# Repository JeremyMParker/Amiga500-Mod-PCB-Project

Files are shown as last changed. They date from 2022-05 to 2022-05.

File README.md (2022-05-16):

# Amiga500-Mod-PCB-Project
A small back panel PCB to house HDMI and several switches...
This small 4-layer PCB will take an HDMI mini cable from a Raspberry Pi RGB-to-HDMI and convert to normal size HDMI for plugging into the Amiga.
There is one small SPST push-button switch to allow menu access to the Raspberry Pi by way of a 2-pin 100mil spaced header.
A miniture DPDT switch is wired to a 4-pin 100mil header to allow the Amiga-Kit DF0/DF1 select switch cable to plug right in.
A miniture 3PDT switch is wired to a 4-pin 100mil header to allow access to the Amiga Audio Filter Mod as described in my YouTube video.
The Audio Filter control either lets the Amiga control the output low-pass filters, or overrides the Amiga and forces the filters to be enabled/disabled.
The PCB is just barely wide enough to fit in the blank space on the left side of the A500 when looking at the back.
This is my first GitHub repository, so please be patient with me!
IMG_4756 copy

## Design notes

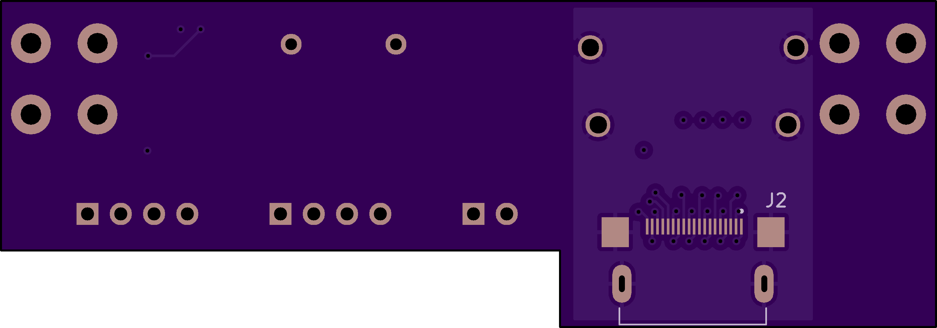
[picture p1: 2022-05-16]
Amiga500 Mod PCB Rev A CAM/OSH Park CAM/Amiga500 Mod PCB RevA bottom.png

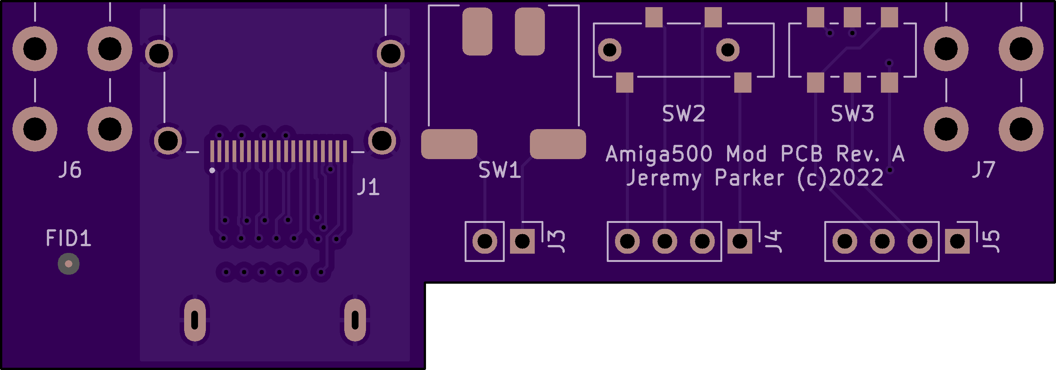
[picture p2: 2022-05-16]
Amiga500 Mod PCB Rev A CAM/OSH Park CAM/Amiga500 Mod PCB RevA top.png

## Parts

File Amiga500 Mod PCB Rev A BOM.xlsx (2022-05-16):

Item | Qty | Reference(s) | Value | LibPart | Footprint | MANUFACTURER | Digi-Key Description | Digi-Key Order #
1 | 1 | J1 | DC04S019JA1R600 | JP Symbol Library:DC04S019JA1R600_2 | SnapEDA Library:JAE_DC04S019JA1R600 | JAE | RECEPT, HDMI 2.1, 48GBPS BANDWID | 670-3154-1-ND
2 | 1 | J2 | 2013978-1 | 2013978-1:2013978-1 | SnapEDA Library:TE_2013978-1 | TE Connectivity | CONN RCPT MINI HDMI 19POS SMD RA | A107963CT-ND
3 | 1 | J3 | Conn_01x02_Male | Connector:Conn_01x02_Male | Connector_PinHeader_2.54mm:PinHeader_1x02_P2.54mm_Vertical | Hirose | CONN HEADER VERT 2POS 2.54MM | H123034-ND
4 | 2 | J4, J5 | Conn_01x04_Male | Connector:Conn_01x04_Male | Connector_PinHeader_2.54mm:PinHeader_1x04_P2.54mm_Vertical | Hirose | CONN HEADER VERT 4POS 2.54MM | H123038-ND
5 | 2 | J6, J7 | Screw_Terminal_01x04 | Connector:Screw_Terminal_01x04 | JP Library:Keystone 4-40 screw terminal | Keystone | TERM SCREW 4-40 4 PIN PCB RA | 36-7774-ND
6 | 1 | SW1 | SW_Push | Switch:SW_Push | JP Library:SPST 800BWSP9SM6RE | E-Switch | SWITCH PUSH SPST-NO 0.4VA 20V | EG2610CT-ND
7 | 1 | SW2 | SW_SP3T | Switch:SW_SP3T | JP Library:SP3T CL-SB-13B-11T | Nidec Copal Electronics | SWITCH SLIDE SP3T 200MA 12V | 563-1332-1-ND
8 | 1 | SW3 | SW_DPDT_x2 | Switch:SW_DPDT_x2 | JP Library:DPDT CL-SB-22B-12T | Nidec Copal Electronics | SWITCH SLIDE DPDT 200MA 12V | 563-1345-1-ND

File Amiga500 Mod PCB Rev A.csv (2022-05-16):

Source: | C:\Users\Jeremy\Documents\PCB Designs\Amiga500 Mod PCB Rev A.kicad_sch
Date: | 5/14/2022 9:10:37 PM
Tool: | Eeschema (6.0.2)
Generator: | C:\Program Files\KiCad\6.0\bin\scripting\plugins/bom_csv_grouped_by_value.py
Component Count: | 11
Individual Components:
Item | Qty | Reference(s) | Value | LibPart | Footprint | Datasheet | MANUFACTURER | MAXIMUM_PACKAGE_HEIGHT | PARTREV | STANDARD
 |  | FID1 | Fiducial | Mechanical:Fiducial | Fiducial:Fiducial_0.5mm_Mask1.5mm | ~
 |  | J1 | DC04S019JA1R600 | JP Symbol Library:DC04S019JA1R600_2 | SnapEDA Library:JAE_DC04S019JA1R600 |  | JAE | 6.3 mm | 1 | Manufacturer Recommendations
 |  | J2 | 2013978-1 | 2013978-1:2013978-1 | SnapEDA Library:TE_2013978-1 |  | TE Connectivity | 3.45mm | B1 | Manufacturer recommendations
 |  | J3 | Conn_01x02_Male | Connector:Conn_01x02_Male | Connector_PinHeader_2.54mm:PinHeader_1x02_P2.54mm_Vertical | ~
 |  | J4 | Conn_01x04_Male | Connector:Conn_01x04_Male | Connector_PinHeader_2.54mm:PinHeader_1x04_P2.54mm_Vertical | ~
 |  | J5 | Conn_01x04_Male | Connector:Conn_01x04_Male | Connector_PinHeader_2.54mm:PinHeader_1x04_P2.54mm_Vertical | ~
 |  | J6 | Screw_Terminal_01x04 | Connector:Screw_Terminal_01x04 | JP Library:Keystone 4-40 screw terminal | ~
 |  | J7 | Screw_Terminal_01x04 | Connector:Screw_Terminal_01x04 | JP Library:Keystone 4-40 screw terminal | ~
 |  | SW1 | SW_Push | Switch:SW_Push | JP Library:SPST 800BWSP9SM6RE | ~
 |  | SW2 | SW_SP3T | Switch:SW_SP3T | JP Library:SP3T CL-SB-13B-11T | ~
 |  | SW3 | SW_DPDT_x2 | Switch:SW_DPDT_x2 | JP Library:DPDT CL-SB-22B-12T | ~
Collated Components:
Item | Qty | Reference(s) | Value | LibPart | Footprint | Datasheet | MANUFACTURER | MAXIMUM_PACKAGE_HEIGHT | PARTREV | STANDARD
1 | 1 | FID1 | Fiducial | Mechanical:Fiducial | Fiducial:Fiducial_0.5mm_Mask1.5mm | ~
2 | 1 | J1 | DC04S019JA1R600 | JP Symbol Library:DC04S019JA1R600_2 | SnapEDA Library:JAE_DC04S019JA1R600 |  | JAE | 6.3 mm | 1 | Manufacturer Recommendations
3 | 1 | J2 | 2013978-1 | 2013978-1:2013978-1 | SnapEDA Library:TE_2013978-1 |  | TE Connectivity | 3.45mm | B1 | Manufacturer recommendations
4 | 1 | J3 | Conn_01x02_Male | Connector:Conn_01x02_Male | Connector_PinHeader_2.54mm:PinHeader_1x02_P2.54mm_Vertical | ~
5 | 2 | J4, J5 | Conn_01x04_Male | Connector:Conn_01x04_Male | Connector_PinHeader_2.54mm:PinHeader_1x04_P2.54mm_Vertical | ~
6 | 2 | J6, J7 | Screw_Terminal_01x04 | Connector:Screw_Terminal_01x04 | JP Library:Keystone 4-40 screw terminal | ~
7 | 1 | SW1 | SW_Push | Switch:SW_Push | JP Library:SPST 800BWSP9SM6RE | ~
8 | 1 | SW2 | SW_SP3T | Switch:SW_SP3T | JP Library:SP3T CL-SB-13B-11T | ~
9 | 1 | SW3 | SW_DPDT_x2 | Switch:SW_DPDT_x2 | JP Library:DPDT CL-SB-22B-12T | ~

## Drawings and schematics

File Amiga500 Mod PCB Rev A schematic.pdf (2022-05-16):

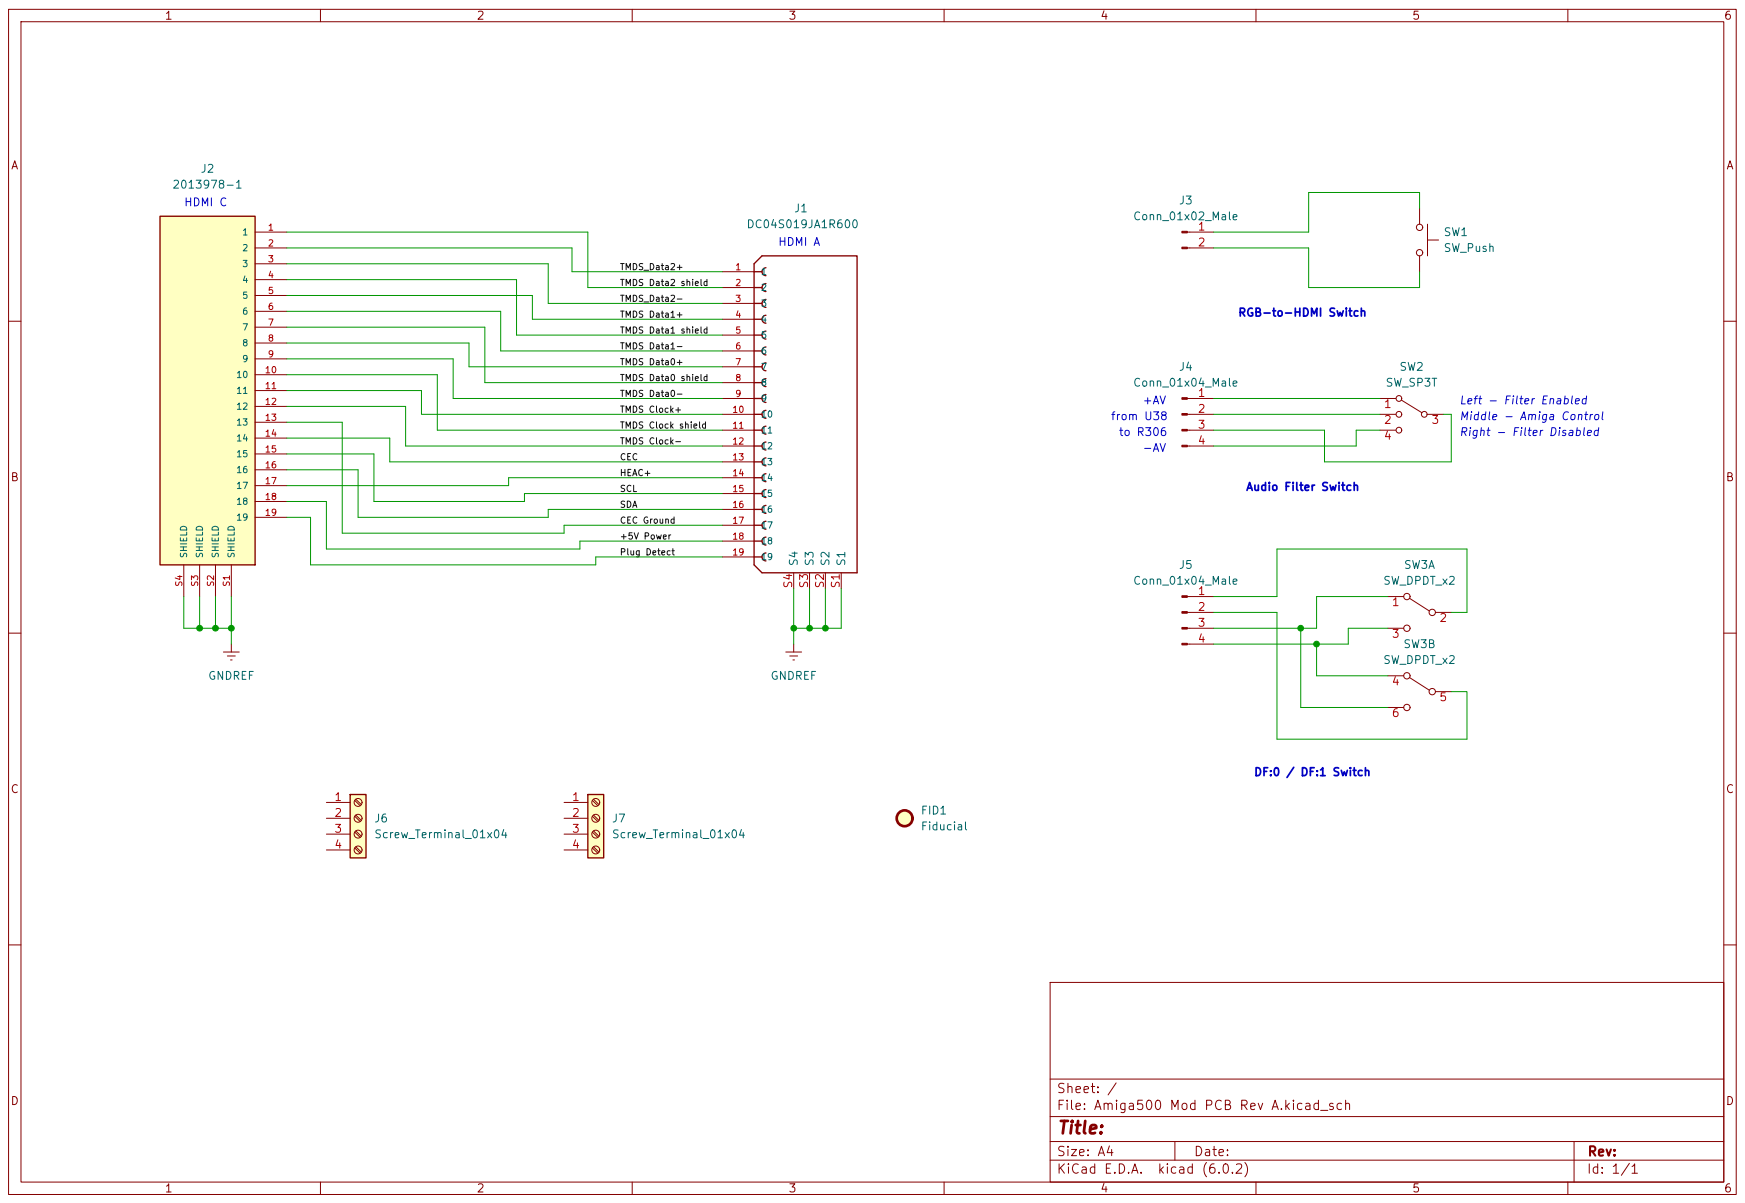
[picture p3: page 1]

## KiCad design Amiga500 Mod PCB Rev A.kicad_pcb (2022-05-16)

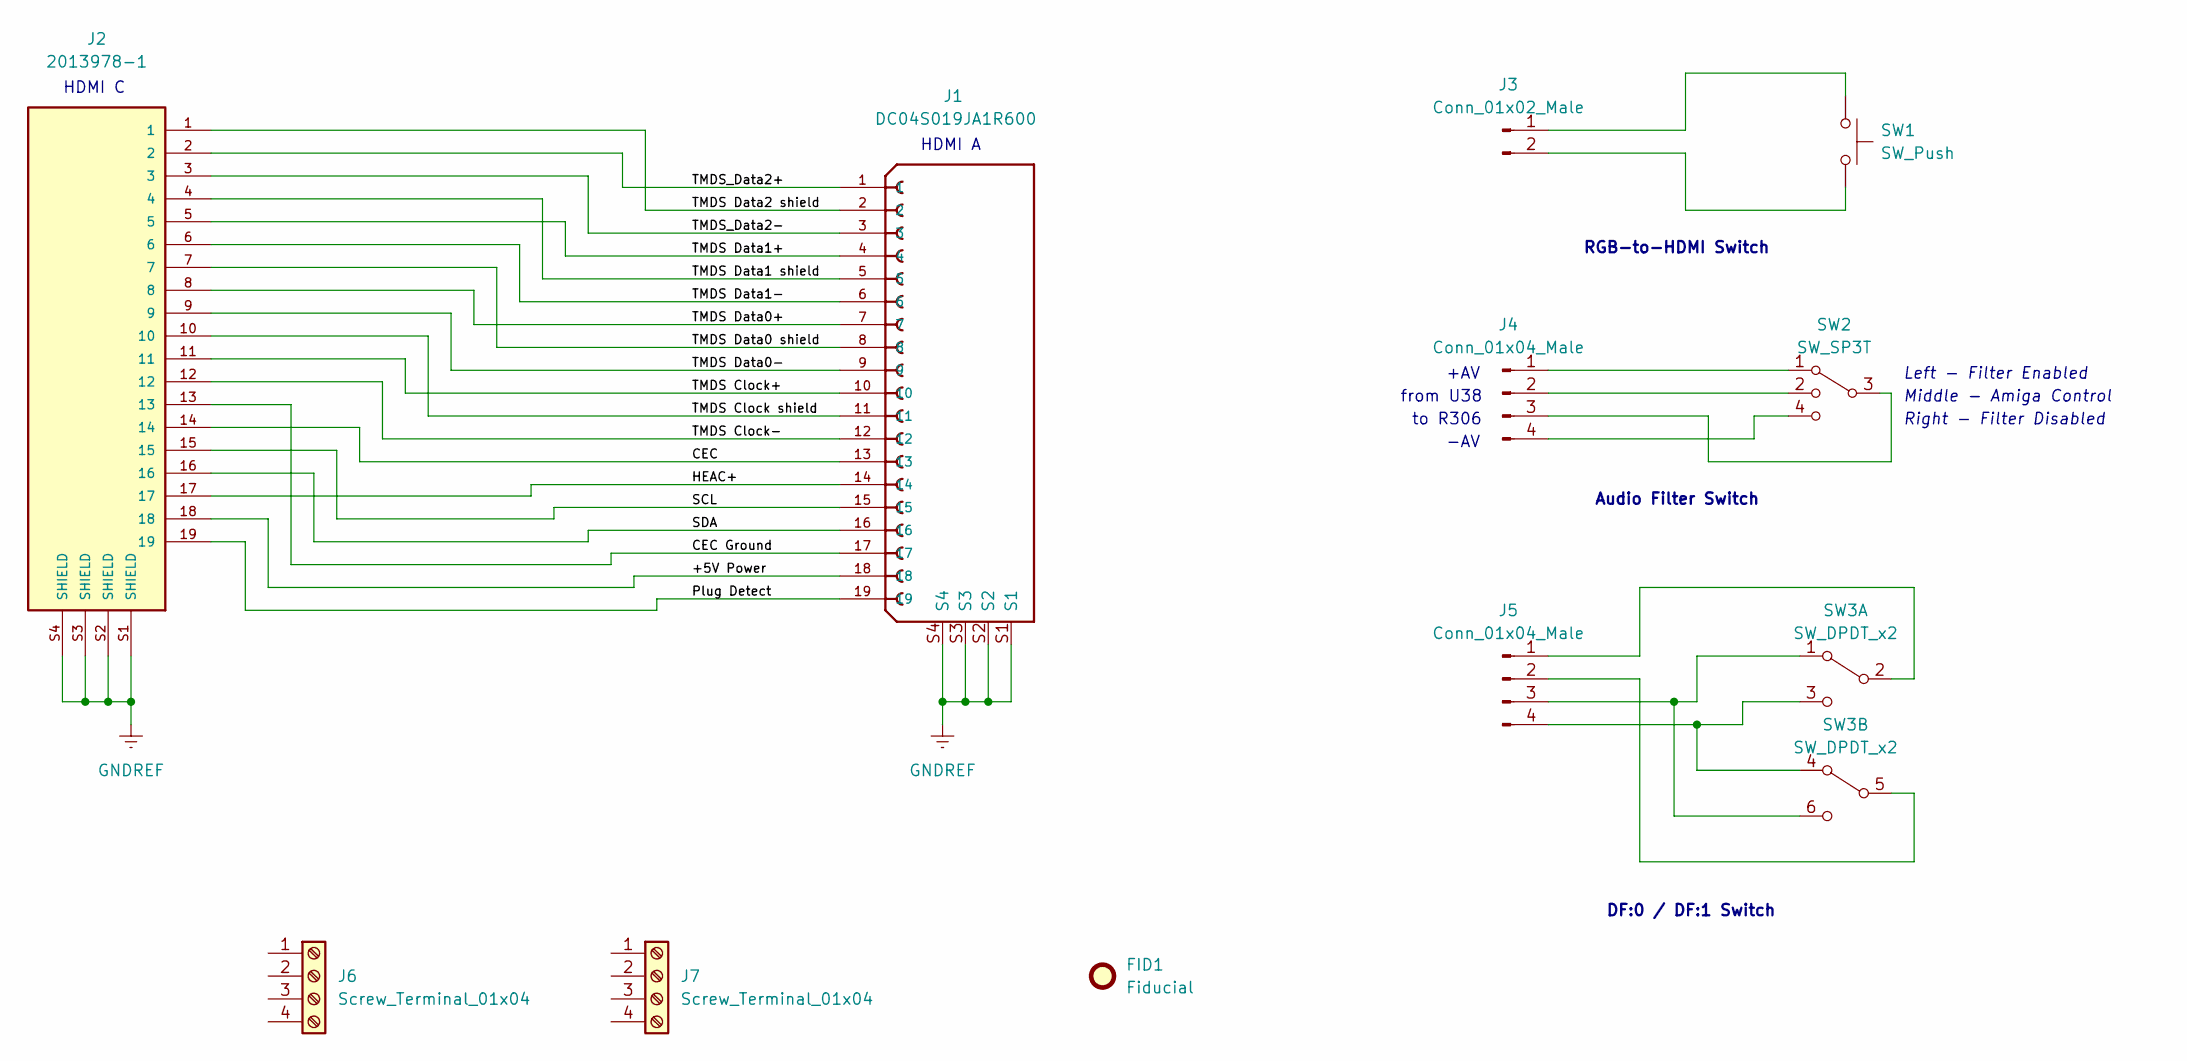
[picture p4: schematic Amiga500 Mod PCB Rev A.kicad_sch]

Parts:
FID1: Fiducial; Fiducial_0.5mm_Mask1.5mm
J1: DC04S019JA1R600; JAE_DC04S019JA1R600; PARTREV 1
J2: 2013978-1; TE_2013978-1; PARTREV B1
J3: Conn_01x02_Male; PinHeader_1x02_P2.54mm_Vertical
J4, J5: Conn_01x04_Male; PinHeader_1x04_P2.54mm_Vertical
J6, J7: Screw_Terminal_01x04; Keystone 4-40 screw terminal
SW1: SW_Push; SPST 800BWSP9SM6RE
SW2: SW_SP3T; SP3T CL-SB-13B-11T
SW3: SW_DPDT_x2; DPDT CL-SB-22B-12T

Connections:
/+5V Power: J1.18, J2.18
/CEC: J1.13, J2.14
/CEC Ground: J1.17, J2.13
/HEAC+: J1.14, J2.17
/Plug Detect: J1.19, J2.19
/SCL: J1.15, J2.15
/SDA: J1.16, J2.16
/TMDS Clock shield: J1.11, J2.10
/TMDS Clock+: J1.10, J2.11
/TMDS Clock-: J1.12, J2.12
/TMDS Data0 shield: J1.8, J2.7
/TMDS Data0+: J1.7, J2.8
/TMDS Data0-: J1.9, J2.9
/TMDS Data1 shield: J1.5, J2.4
/TMDS Data1+: J1.4, J2.5
/TMDS Data1-: J1.6, J2.6
/TMDS Data2 shield: J1.2, J2.1
/TMDS_Data2+: J1.1, J2.2
/TMDS_Data2-: J1.3, J2.3
GNDREF: J1.S1, J1.S2, J1.S3, J1.S4, J2.S1 (SHIELD), J2.S2 (SHIELD), J2.S3 (SHIELD), J2.S4 (SHIELD)
unnamed: J3.1, SW1.1
unnamed: J3.2, SW1.2
unnamed: J4.1, SW2.1
unnamed: J4.2, SW2.2
unnamed: J4.3, SW2.3
unnamed: J4.4, SW2.4
unnamed: J5.1, SW3.2 (B)
unnamed: J5.2, SW3.5 (B)
unnamed: J5.3, SW3.1 (A), SW3.6 (C)
unnamed: J5.4, SW3.3 (C), SW3.4 (A)

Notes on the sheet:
HDMI C
from U38
to R306
Left - Filter Enabled
RGB-to-HDMI Switch
Right - Filter Disabled
DF:0 / DF:1 Switch
Middle - Amiga Control
+AV
HDMI A
-AV
Audio Filter Switch

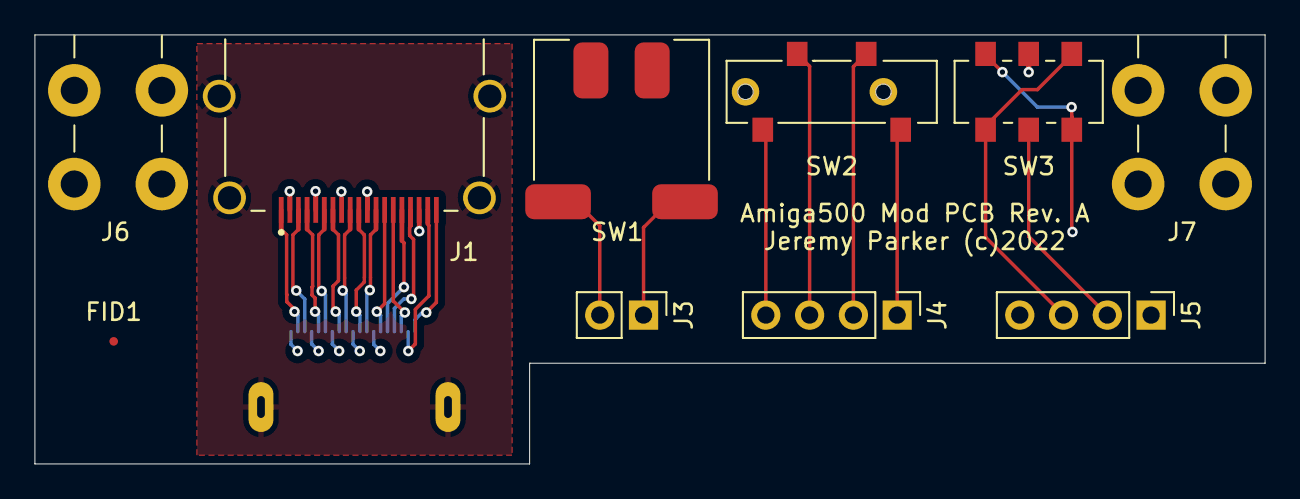
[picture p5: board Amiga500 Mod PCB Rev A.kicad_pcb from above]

Board: 4 copper layers, 71.4 x 24.9 mm, 11 parts (1 on the bottom side), 30 nets.

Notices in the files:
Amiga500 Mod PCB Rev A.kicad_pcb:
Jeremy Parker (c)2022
